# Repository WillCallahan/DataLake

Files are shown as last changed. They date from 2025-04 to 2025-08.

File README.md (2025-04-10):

# DataLake

The DataLake system is an integrated platform designed for the systematic collection of meteorological and limnological data from lacustrine environments to support scientific research. This system quantifies key environmental parameters, including air temperature, photosynthetically active radiation (PAR), and water temperatures across the epilimnion, metalimnion, and hypolimnion; the three primary thermal strata of lakes.

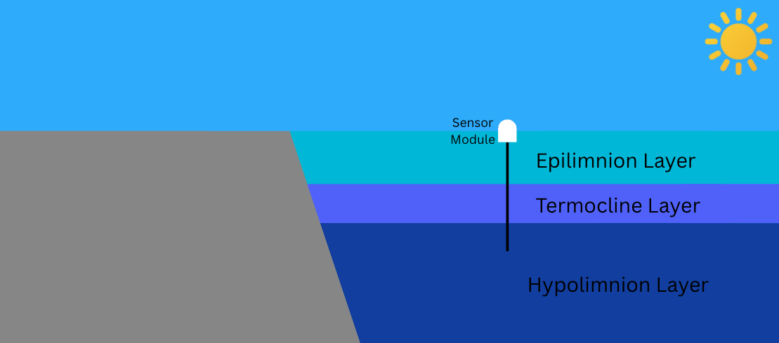
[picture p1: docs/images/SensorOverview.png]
SensorOverview


## Lake Sensor: Design and Instrumentation

The lake sensor comprises a bespoke embedded circuit engineered for high-precision environmental monitoring. It integrates four temperature sensors, a photodiode for light intensity measurement, and a radio frequency (RF) module for data transmission. The core of the system is a PIC16F1938 microcontroller, which orchestrates data acquisition from multiple sensors and facilitates wireless communication with a Raspberry Pi base station via an RYLR998 transceiver.

Water temperature profiling across the lake’s vertical stratification is achieved using three TMP35 precision analog temperature sensors, deployed at discrete depths corresponding to the lake’s thermal layers. The microcontroller’s onboard temperature sensor measures ambient air temperature at the lake surface, providing a critical atmospheric reference point. Additionally, a calibrated light sensor quantifies incident solar irradiance, a key variable influencing aquatic ecosystem dynamics.

The circuit architecture prioritizes extreme low-power (XLP) operation, enabling sustained functionality at 1.6 V, powered by two 3600 mAh lithium-ion batteries, with a projected operational lifespan of two years. Firmware programming implements a duty-cycling protocol, whereby the microcontroller activates every five minutes to sample sensor outputs and transmit the aggregated dataset over a distance of up to 1.6 kilometers (1 mile) to a remote receiver. This design ensures robust, long-term data collection in remote field conditions, supporting high-resolution temporal analysis of lake system responses to environmental forcing.

## Development Stages

### Version Alpha (IN PROGRESS)

The [alpha version](https://github.com/WillCallahan/DataLake/tree/simple-sensor) of the system is designed to be created as rapidly as possible in order to create a functional product.

Sensor Alpha Version

#### Sensor Design

1. Initial research (ONGOING)
2. Proof of concept embedded curcuit (COMPLETE)
3. Reliability testing (ONGOING)
4. Collect system packaging (COMPLETE)
5. Create deployment package (TBD)
6. Deployment (TBD)

#### Base Station Design

1. Initial research (COMPLETE)
2. Proof of concept (COMPLETE)
3. Reliabliity testing (COMPLETE)
4. Deployment (TBD)

### Version Beta

The beta version of the system is designed to be deployed at scale with reduced development and material costs, focusing on creating a custom base station.

#### Sensor Design

1. Research board design
2. Select components
3. Create printable circuit board
4. Print circuit
5. Test Circuit

#### Base Station Design

1. Initial research
2. Proof of concept
3. Reliabliity testing
4. Deployment

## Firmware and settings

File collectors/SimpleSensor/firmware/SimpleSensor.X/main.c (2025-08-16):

/*
 * File:   main.c
 * Author: wcallahan
 *
 * Created on September 16, 2024, 10:31 PM
 * 
 * @see https://www.microchip.com/en-us/code-examples Code Examples
 */


#include <xc.h>
#include <stdio.h>
#include <string.h>
#include "settings.h"
#include "uart.h"
#include "lora.h"
#include "string.h"
#include "sensors.h"

#ifndef MAIN_C

// Configuration bits for PIC16F1938
#pragma config FOSC = INTOSC    // Internal oscillator
#pragma config WDTE = 0x3       // Watchdog Timer enabled
#pragma config PWRTE = OFF      // Power-up Timer off
#pragma config MCLRE = ON       // MCLR pin enabled
#pragma config CP = OFF         // Code Protection off
#pragma config CPD = OFF        // Data Code Protection off
#pragma config BOREN = 0x2      // Brown-out Reset enabled when active, disabled during sleep
#pragma config CLKOUTEN = OFF   // CLKOUT function is disabled
#pragma config IESO = OFF       // Internal/External Switch Over mode off
#pragma config FCMEN = OFF      // Fail-Safe Clock Monitor disabled
#pragma config WRT = OFF        // Flash Memory Self-Write Protection off
#pragma config PLLEN = OFF      // PLL disabled
#pragma config STVREN = ON      // Stack Overflow/Underflow Reset enabled
#pragma config BORV = LO        // Brown-out Reset Voltage (low)
#pragma config LVP = ON         // Low-Voltage Programming enabled

#pragma config IDLOC0 = 0 // Device ID A
#pragma config IDLOC1 = 0 // Device ID B
#pragma config IDLOC2 = 0 // Software Revision A
#pragma config IDLOC3 = 0 // Software Revision B

#define RX TRISC7
#define TX TRISC6
#define DEBUG_SWITCH RB5
#define BAUD 9600
#define DIVIDER (_XTAL_FREQ / ((4UL * BAUD) - 1)) // Based off manual

#define LORA_ADDRESS 1 // Target LoRa receiver address

#define STR_BUFFER_SIZE 32
#define USART_SUCCESS_READ_HANDLER &handleInterrupt

#define TEMP_TOGGLE_PORT PORTC
// These are the address offsets start at adress TEMP_TOGGLE_PORT
#define TEMP_0_TOGGLE 0
#define TEMP_1_TOGGLE 1
#define TEMP_2_TOGGLE 2

#define TEMP_0_CHS 0b00 // Temp Sensor A ADC Channel Selection
#define TEMP_1_CHS 0b01 // Temp Sensor B ADC Channel Selection
#define TEMP_2_CHS 0b10 // Temp Sensor C ADC Channel Selection

#define SENSOR_ID_0 'A'
#define SENSOR_ID_1 'B'
#define SENSOR_ID_2 'C'

#define DEBUG_LED RA5

#endif

void initializePIC(void) {
    // Setup oscillator
    OSCCONbits.IRCF = 0b1101; // 4 MHz HF
    OSCCONbits.SCS = 0b10; // Internal oscillator
    OSCCONbits.SPLLEN = 0; // Disable 4x PLL Clock Multiplier
    
    // Set input/output
    TRISA = 0b00000111; // Set RA<0..2> to input for temperature sensors
    TRISB = 0b00100000; // Set RB5 to input for Debug Switch
    TRISC = 0x00;       // Set RC<0..2> to output for temp power toggle
    PORTA = 0x00;
    PORTB = 0x00;
    PORTC = 0x00;
    ANSELA = 0b00000111; // Enable RA<0..2> analog input for temperature sensors
    ANSELB = 0x00;
   
    WPUE = 0; //Enable Weak Pull-ups
    WPUB0 = 1; // Set RB5 as a Weak Pull-Up
    
    // Watchdog scaler of 0b10000 - 1:2097152 (64 seconds)
    // Watchdog scaler of 0b01100 - 1:131072 (4 seconds)
    // Watchdog scaler of 0b01010 - 1:32768 (1 seconds)
    WDTCONbits.WDTPS = 0b01100;
}

void initializeUsart() {
    TX = 0;
    RX = 1;
// TODO   SPBRG = DIVIDER;
    SPBRG = 8; // TESTING for 4MHz
    
    SYNC = 0; // Use Asynchronous Mode
    BRGH = 1; //Force High Speed Transmission
    BRG16 = 1; // Disable 16-bit Buad Rate Generator
    
    TXEN = 1; // Enable Transmission Circuitry
    CREN = 1; // Enable Receiver Circuitry
    SPEN = 1; // Enable EUSART
    RCIE = 1; // Enable Receiver Interrupt
    INTCON = 0b11000000; // Enable Peripheral interrupt and Global Interrupts
}

void __interrupt() ISR(void) {
    handleUsartInterrupt(USART_SUCCESS_READ_HANDLER);
}

void blinkLedTimes(int times) {
    __delay_ms(1000);
    for (int i = 0; i != times; i++) {
        DEBUG_LED = 1;
        __delay_ms(500);
        DEBUG_LED = 0;
        __delay_ms(500);
        CLRWDT();
    }
}

void blinkLedStatus() {
    DEBUG_LED = 0;
    if (DEBUG_SWITCH == 0) {
        return;
    }
    if (lora_status.LORA_ERROR_CODE) {
        blinkLedTimes(2);
    }
    if (uart_status.ERR) {
        blinkLedTimes(3);
    }
    DEBUG_LED = 0;
}

void transmitTemperatureWithDebug(char* outputBuffer, int temperature, char sensorId) {
    if (temperature != INT16_MIN) {
        wakeLora(putPhrase);
        sprintf(outputBuffer, "T%c%d", sensorId, temperature);
        sendData(putPhrase, LORA_ADDRESS, outputBuffer);
        temperature = INT16_MIN;
    }
    if (lora_status.LORA_ERROR_CODE > 0 || lora_status.READ_OVERFLOW == 1 || lora_status.WRITE_OVERFLOW == 1) {
        wakeLora(putPhrase);
        sprintf(outputBuffer, "ERR=%d,%d,%d", lora_status.LORA_ERROR_CODE, lora_status.READ_OVERFLOW, lora_status.WRITE_OVERFLOW);
        sendData(putPhrase, LORA_ADDRESS, outputBuffer);
    }
    blinkLedStatus();
}

void readAndTransmitTemperature(char* outputBuffer, uint8_t tempToggle, uint8_t tempChannel, char sensorId) {
    CLRWDT();
    int temperature = readTemperature(&TEMP_TOGGLE_PORT, tempToggle, tempChannel);
    transmitTemperatureWithDebug(outputBuffer, temperature, sensorId);
}

void main(void) {
    initializePIC();
    initializeAdc();
    initializeUsart();
    initializeLora(putPhrase, LORA_ADDRESS);
    
    char outputBuffer[8];
    
    strcpy(outputBuffer, "INIT");
    sendData(putPhrase, LORA_ADDRESS, outputBuffer);
    
    while (1) {
        if (DEBUG_SWITCH == 1) {
            DEBUG_LED = 1; // Blink an LED for status
        }

        readAndTransmitTemperature(outputBuffer, TEMP_0_TOGGLE, TEMP_0_CHS, SENSOR_ID_0);
        readAndTransmitTemperature(outputBuffer, TEMP_1_TOGGLE, TEMP_1_CHS, SENSOR_ID_1);
        readAndTransmitTemperature(outputBuffer, TEMP_2_TOGGLE, TEMP_2_CHS, SENSOR_ID_2);
        
        sleepLora(putPhrase);
        SLEEP();
        NOP();
    }
}

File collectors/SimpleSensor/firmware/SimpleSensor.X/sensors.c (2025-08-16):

/*
 * File:   sensors.c
 * Author: wcallahan
 *
 * Created on October 18, 2024, 11:50 PM
 */
#include <xc.h>
#include "settings.h"
#include "sensors.h"

void initializeAdc(void) {
    // Right-justified result and FOSC/8
    ADCON1 = 0b10010000;
}

int readTemperature(volatile unsigned char* portRegister,
        uint8_t toggleRegister,
        uint8_t channelSelect) {
    
    // Turn on the TMP35 sensor
    *portRegister = (unsigned char)(1 << toggleRegister);
    
    // Charge the capacitor, Let the TMP35 sensor startup
    __delay_us(100);
    
    // Enable the ADON ADC conversion bit and select the input channel
    ADCON0 = 1 | (unsigned char)(channelSelect << 2);
    
    // Allow the ADC acquisition to occur, see Table 15-1 with FOSC/8 at 4MHz
    __delay_us(2);
    
    GO_nDONE = 1;
    
    while (GO_nDONE);
    
    int temperature = ((ADRESH << 8) + ADRESL);
    
    
    // Turn off the TMP35 sensor
    *portRegister = (unsigned char)(0 << toggleRegister);
    
    return temperature;
}

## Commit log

2024-10-29 Added basic code to read the ADC controller
2024-10-31 Continued work on temperature read
2024-10-31 Added KiCad pcd initial design
    [SimpleSensor.kicad_pcb, SimpleSensor.kicad_sch]
2024-10-31 Reassign the debug LED to RA4
2024-11-12 Fixed sensor 3 ID
    [main.c]
2024-11-14 Debugging LED
2025-04-08 Added Sensor Overview image
